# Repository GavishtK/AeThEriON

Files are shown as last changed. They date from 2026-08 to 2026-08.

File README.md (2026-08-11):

<p align="center">
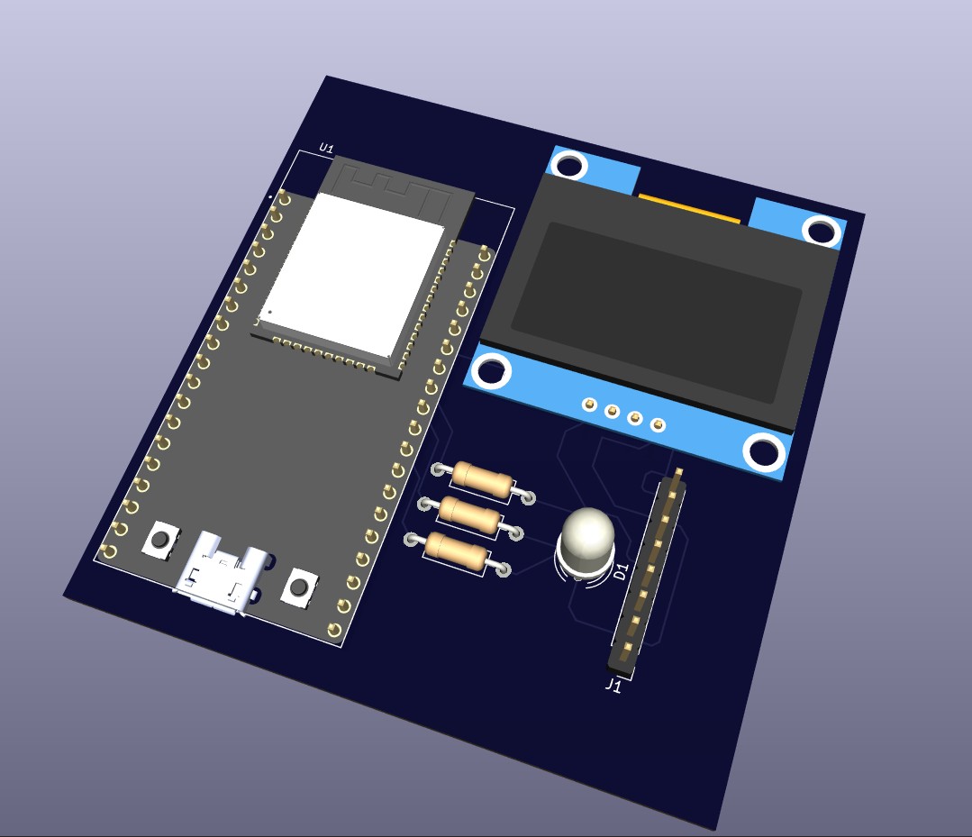
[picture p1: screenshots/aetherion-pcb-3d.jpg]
Aetherion PCB 3D Render
  
</p>

<h1 align="center">AETHERION AI</h1>

<p align="center">
  <b>ESP32-Based Attitude Indicator &amp; Wireless Flight Instrumentation System</b>
  <br/>
  
  
  
  
  
</p>

<p align="center">
  <b>Real-time flight attitude indicator with a wireless OLED display and a full web-based analytics dashboard.</b>
</p>
<p align="center">
  <b>50 Hz telemetry | 25 FPS OLED | 60 FPS horizon | AI analysis | Flight recording &amp; replay | SQLite-quality sensor diagnostics</b>
</p>

---

## Table of Contents

1. [Project Overview](#overview)
2. [System Architecture](#system-architecture)
3. [Data Flow](#data-flow)
4. [Telemetry Protocol](#telemetry-protocol)
5. [Firmware](#firmware)
6. [Dashboard](#dashboard)
7. [Screenshots](#screenshots)
8. [PCB Design](#pcb-design)
9. [Hardware](#hardware)
10. [Quick Start](#quick-start)
11. [Development](#development)
12. [UI Testing](#ui-testing)
13. [License](#license)

---

## Overview 

AETHERION AI is a self-contained, open-source flight instrumentation system built on the ESP32. It combines:

- **Onboard OLED primary flight display (PFD)** — 128×64 monochrome display rendered at 25 FPS
- **Wireless web dashboard** — served directly from the ESP32 over Wi-Fi, accessed via any browser
- **Real-time attitude indicator** — artificial horizon with pitch ladder, roll arc, aircraft symbol, and turn coordinator
- **Flight telemetry** — 50 Hz broadcast of raw IMU data, computed attitude, and G-force over WebSocket
- **Flight recording & replay** — client-side session storage (IndexedDB), CSV/JSON export, and seekable playback
- **AI-powered analysis** — multi-model flight state classification (Random Forest, XGBoost, Neural Network, SVM)
- **Stability & control scoring** — RMS deviation, oscillation analysis, correction rate, and pilot stability metrics
- **Sensor health diagnostics** — saturation, noise, packet-loss, and data-quality analysis

The ESP32 runs in **Access Point mode**, creating its own Wi-Fi network so no router is required. The dashboard is stored on-board in LittleFS flash and served over HTTP, while telemetry is streamed over a WebSocket server at 50 Hz.

---

## System Architecture 

### Firmware Module Architecture

```mermaid
graph LR
    subgraph "firmware/Aetherion"
        A[Aetherion.ino<br/>Main Entry]
        B[config.h<br/>Configuration]
        C[imu.cpp/h<br/>Sensor Driver<br/>MPU6050 + Madgwick]
        D[graphics.cpp/h<br/>OLED Rendering<br/>U8g2 / PFD]
        E[web.cpp/h<br/>HTTP + WS Server<br/>LittleFS]
        F[rgb.cpp/h<br/>LED Status]
    end

    A --> B
    A --> C
    A --> D
    A --> E
    A --> F
    C -->|IMUData| D
    C -->|IMUData| A
    D -->|drawPFD| A
    E -->|handleWebClient| A
    F -->|Status| A
```

### Architecture Diagram (Image)

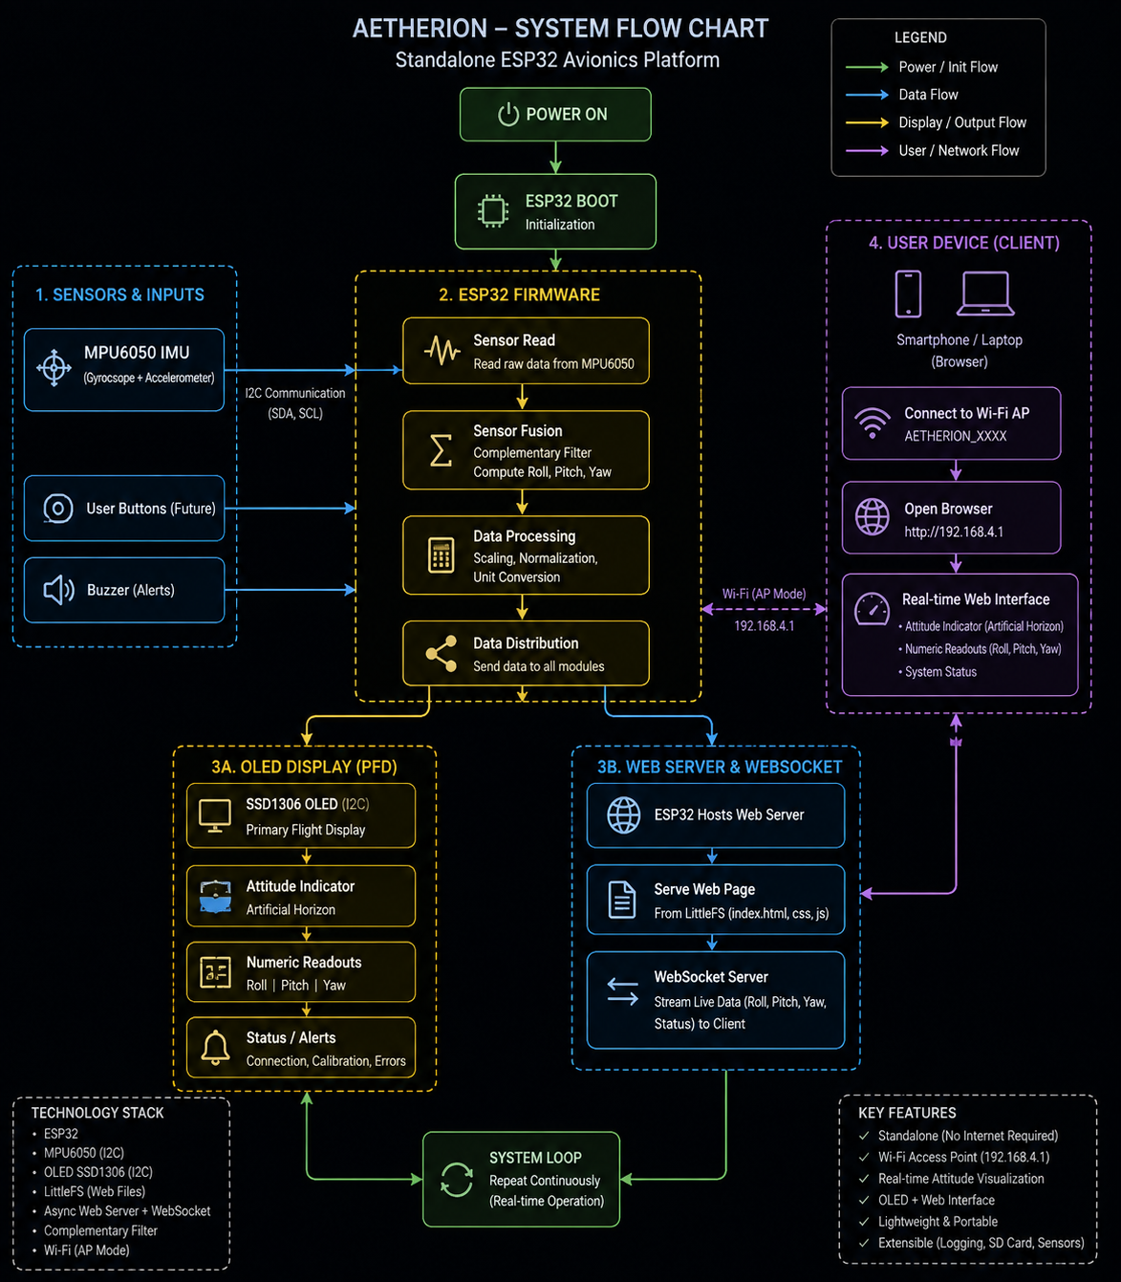
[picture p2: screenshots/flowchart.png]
System Architecture Flowchart


---

## Data Flow 

```mermaid
sequenceDiagram
    participant ESP32 as ESP32
    participant IMU as MPU6050 (I2C)
    participant OLED as OLED Display
    participant Browser as Web Browser
    participant IndexedDB as IndexedDB (Local)

    loop Setup (one-time)
        ESP32->>IMU: Initialize (I2C 0x68)
        ESP32->>IMU: Calibrate (200 samples)
        ESP32->>OLED: Boot Screen → Loading → Ready
        ESP32->>ESP32: Create I2C Mutex
        ESP32->>ESP32: Create oledTask (FreeRTOS, 25 FPS)
        ESP32->>WiFi: softAP("Aetherion", "aetherion123")
        ESP32->>WS: WebSocket Server begin (port 81)
        ESP32->>HTTP: LittleFS mount + WebServer begin (port 80)
    end

    par oledTask (25 FPS, Core 0)
        loop every 40 ms
            oledTask->>IMU: xSemaphoreTake(i2cMutex)
            IMU->>oledTask: Read accel + gyro
            oledTask->>oledTask: Compute roll/pitch (atan2)
            oledTask->>OLED: drawPFD(roll, pitch, gForce)
            oledTask->>oledTask: xSemaphoreGive(i2cMutex)
        end
    end

    par Main Loop (50 Hz)
        loop every 20 ms
            ESP32->>Web: handleWebClient() (HTTP)
            ESP32->>WS: webSocket.loop() (WebSocket)
            ESP32->>IMU: xSemaphoreTake(i2cMutex, 5 ms)
            IMU->>ESP32: updateIMU() — raw accel, gyro, computed attitude
            ESP32->>ESP32: xSemaphoreGive(i2cMutex)
            ESP32->>Browser: WebSocket broadcastTXT(JSON) at 50 Hz
        end
    end

    Note over Browser,DB: Browser receives 50 Hz telemetry
    Browser->>Browser: Parse JSON packet
    Browser->>Browser: Update horizon (60 FPS via requestAnimationFrame)
    Browser->>Browser: Update telemetry readouts (15 Hz)
    Browser->>Browser: Update live graphs (15 FPS)
    Browser->>Browser: Detect flight state (10 Hz rule-based)
    Browser->>IndexedDB: Store snapshot on record
```

### Telemetry Packet Format

Every 20 ms (50 Hz), the ESP32 broadcasts a JSON packet:

```json
{
  "t": 1543210,
  "roll": -4.23,
  "pitch": 2.15,
  "gForce": 1.02,
  "ax": 0.123,
  "ay": -0.045,
  "az": 9.782,
  "gx": 0.001,
  "gy": -0.003,
  "gz": 0.002
}
```

| Field | Type | Unit | Description |
|---|---|---|---|
| `t` | uint32 | ms | ESP32 uptime (for clock sync) |
| `roll` | float  | degrees  | Roll angle (-180° to +180°) |
| `pitch` | float  | degrees  | Pitch angle (-90° to +90°) |
| `gForce`  | float  | G | Resultant G-force (1.0 = level) |
| `ax/ay/az`| float  | m/s² | Accelerometer raw values |
| `gx/gy/gz`| float  | rad/s | Gyroscope raw values |

---

## Firmware 

The ESP32 firmware is an Arduino sketch (`Aetherion.ino`) with modular C++ components.

### File Structure

```
firmware/Aetherion/
├── Aetherion.ino      # Main entry point: setup() + loop()
├── config.h           # Pin assignments, WiFi creds, constants
├── imu.cpp            # MPU6050 driver + sensor fusion
├── imu.h              # IMU data structure + API
├── graphics.cpp       # OLED rendering (PFD, boot screen, loading)
├── graphics.h         # Graphics API declarations
├── web.cpp            # HTTP + WebSocket server (LittleFS)
├── web.h              # Web server API declarations
├── rgb.cpp            # RGB LED status indicator
├── rgb.h              # RGB LED API declarations
├── sync_dashboard.ps1 # Syncs dashboard files to LittleFS data/
└── data/              # Dashboard served from LittleFS
    ├── index.html
    ├── style.css
    └── js/
        ├── app.js           # Core app: WebSocket, render loop
        ├── horizon.js        # Canvas artificial horizon
        ├── graphs.js         # Live telemetry graphs
        ├── flight-state.js   # Rule-based state detection
        ├── recorder.js       # Flight recording + IndexedDB
        ├── analysis.js       # Replay, stability, ML panels
        └── settings.js       # Persistent settings (localStorage)
```

### Key Features

| Feature | Details |
|---|---|
| **IMU Sensing** | MPU6050 accelerometer + gyroscope via I2C (400 kHz) |
| **Attitude Calc.**  | Roll/Pitch via `atan2` with 200-sample static calibration offset |
| **G-Force** | Resultant acceleration vector magnitude normalized to G |
| **OLED Display** | 128×64 SH1106, drawn at 25 FPS via dedicated FreeRTOS task |
| **PFD Elements** | Pitch ladder, roll arc with tick marks, aircraft symbol, turn coord.  |
| **WiFi** | ESP32 in AP mode — SSID `Aetherion`, password `aetherion123` |
| **WebSocket** | Broadcasts JSON telemetry at 50 Hz (port 81) |
| **HTTP Server** | Serves dashboard from LittleFS (port 80) |
| **FreeRTOS** | `oledTask` on Core 0 at priority 1 with I2C mutex |
| **RGB LED** | Red (boot) → Purple (init) → Blue (connecting) → Green (ready) |
| **I2C Mutex** | Serializes access between main loop (IMU read) and oledTask (OLED draw) |

### Boot Sequence

```mermaid
flowchart TD
    A[Power On] --> B[Serial Init 115200]
    B --> C[initDisplay + initRGB]
    C --> D[RGB Red: Boot Screen]
    D --> E[Delay 1500ms]
    E --> F[RGB Purple: Initializing]
    F --> G[initIMU]
    G --> H[calibrateIMU 200 samples]
    H --> I[Wire.setClock 400kHz]
    I --> J[WiFi.softAP]
    J --> K[WebSocket Server on :81]
    K --> L[initFileSystem + initWebServer]
    L --> M[RGB Purple: Loading Screen 0-96]
    M --> N[RGB Blue: Ready Screen]
    N --> O[Delay 1000ms]
    O --> P[RGB Green: Ready]
    P --> Q[Create I2C Mutex]
    Q --> R[Create oledTask FreeRTOS]
    R --> S[Main Loop: 50 Hz]
```

---

## Dashboard 

The web dashboard is a single-page application (SPA) written in vanilla JavaScript with no external framework dependencies. It uses HTML5 Canvas for all rendering and IndexedDB for local session storage.

### Architecture

```mermaid
graph TB
    subgraph "Dashboard Modules"
        App[app.js<br/>Core Engine<br/>WebSocket, Render Loop]
        Horizon[horizon.js<br/>Artificial Horizon<br/>Canvas 2D]
        Graphs[graphs.js<br/>Live Telemetry Graphs<br/>Canvas 2D]
        FlightState[flight-state.js<br/>State Detection<br/>Rule-based]
        Recorder[recorder.js<br/>Flight Recorder<br/>IndexedDB]
        Analysis[analysis.js<br/>Replay + AI Analysis]
        Settings[settings.js<br/>Config + localStorage]
        Style[style.css<br/>Dark Theme UI]
    end

    App --> Horizon
    App --> Graphs
    App --> FlightState
    App --> Recorder
    App --> Analysis
    App --> Settings
    App --> Style
    App -->|WebSocket| ESP32[ESP32 Telemetry]
    Horizon -->|registerCallback horizon| App
    Graphs -->|registerCallback graph| App
    FlightState -->|registerCallback state| App
    Recorder -->|registerCallback packet+graph| App
    Analysis -->|loadSession| Recorder
    Settings -->|load/save| App
```

### Render Loop Architecture

The dashboard uses a **throttled multi-rate render loop** driven by `requestAnimationFrame`:

| Component | Rate | Trigger | Description |
|---|---|---|---|
| Artificial Horizon  | 60 FPS | `requestAnimationFrame` | Canvas redraw, smooth attitude |
| Telemetry Readouts  | 15 Hz  | Time-based throttle | Text updates for accel/gyro/attitude|
| Live Graphs | 15 FPS | Time-based throttle | Canvas graph plots (roll/pitch/G/gyro)|
| Flight State | 10 Hz  | Time-based throttle | Rule-based state detection |
| Diagnostics | 2 Hz | Time-based throttle | Packet count, FPS, latency, uptime  |
| Packet Callbacks | 50 Hz  | On every packet | Recording data capture |

### Tab Navigation

The dashboard has four tabs:

1. **LIVE** — Real-time attitude indicator, telemetry panel, live graphs, flight state, and status bar
2. **RECORD** — Flight recording controls, session management, recording preview graph
3. **ANALYSIS** — Flight replay, stability metrics, control analysis, sensor health, system performance, AI analysis panel
4. **SETTINGS** — Connection configuration, telemetry settings, display options

### Flight States

The rule-based flight state detector identifies these states:

| State | Color | Trigger Condition |
|---|---|---|
| LEVEL | Green | Roll < 30°, pitch < 8°, G within 0.5–1.8 |
| TURNING LEFT | Cyan | Roll < -30° |
| TURNING RIGHT  | Cyan | Roll > +30° |
| CLIMBING | Amber | Pitch > 15° |
| DESCENDING | Amber | Pitch < -15° |
| PITCH-UP | Orange  | Pitch > 8° |
| PITCH-DOWN | Orange  | Pitch < -8° |
| ROLLING | Magenta | |gx|, |gy| > 0.15 or |gz| > 0.1 |
| RECOVERING | Cyan | Roll < 15° and trending toward level |
| UNSTABLE | Red | G-force > 1.8 or < 0.5 |

### AI Analysis Models

The Analysis tab supports four ML models for flight state classification:

| Model | Use Case | Accuracy Estimate |
|---|---|---|
| Random Forest | Fast, robust baseline classification  | ~92% |
| XGBoost | Gradient boosting, handles edge cases | ~94% |
| Neural Network | Deep pattern recognition | ~90% |
| SVM | Linear separability, low compute | ~88% |

### Stability Metrics

| Metric | Description |
|---|---|
| Roll RMS | Root-mean-square roll deviation |
| Pitch RMS | Root-mean-square pitch deviation |
| Angular-rate RMS | RMS of combined gyroscope rates (gx+gy+gz) |
| Roll Peak | Maximum absolute roll |
| Pitch Peak | Maximum absolute pitch |
| G-Force Peak | Maximum G-force recorded |
| Stability Score | Composite 0-100 score: 100 - weighted deviation penalties |
| Data Quality | Sensor health score factoring missing packets, saturation, noise |

### Control Analysis

| Metric | Description |
|---|---|
| Roll Control | RMS-based quality rating (Good/Moderate/Fair/Poor) |
| Pitch Control | RMS-based quality rating |
| Correction Rate | Frequency of roll direction changes per second |
| Oscillation | Std dev of roll deltas (control stability) |
| Recovery | RMS of roll in final 20% of flight (settling quality) |

---

## Screenshots 

### Dashboard — Live Tab

Real-time attitude indicator with artificial horizon, telemetry panel, live graphs, flight state, and status bar:

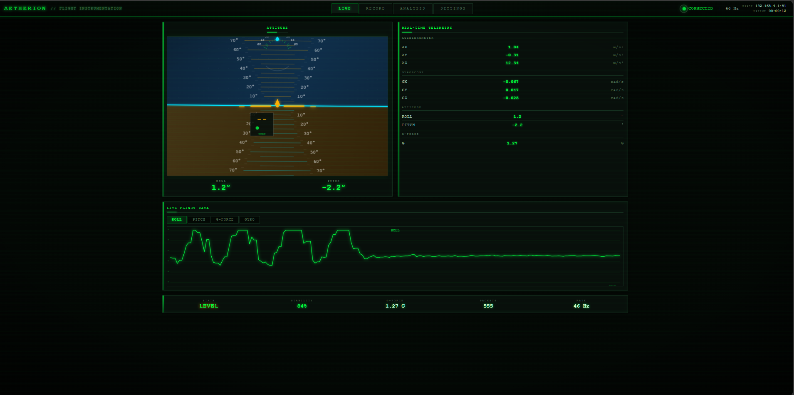
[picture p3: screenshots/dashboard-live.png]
Dashboard Live Tab


### Dashboard — Record Tab

Flight recording controls, session list, and recording preview graph:

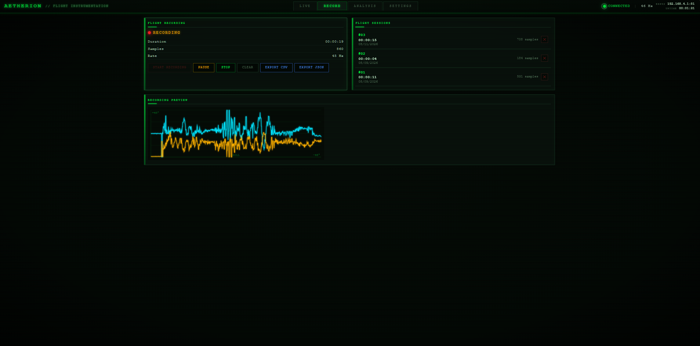
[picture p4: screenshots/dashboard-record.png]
Dashboard Record Tab


### Dashboard — Analysis Tab

Flight replay, stability metrics, control analysis, sensor health, system performance, and AI analysis:

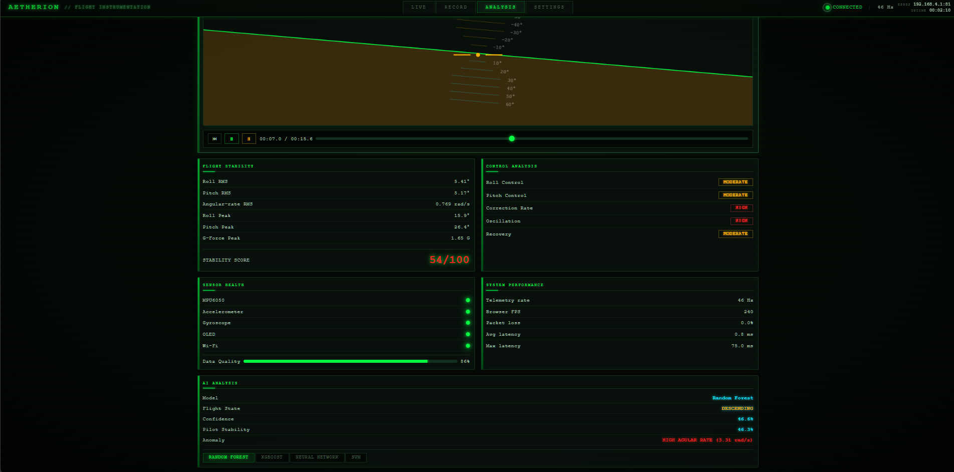
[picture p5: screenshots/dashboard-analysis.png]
Dashboard Analysis Tab


### Dashboard — Settings Tab

Connection settings (ESP32 IP, WebSocket port), telemetry configuration, and display options:

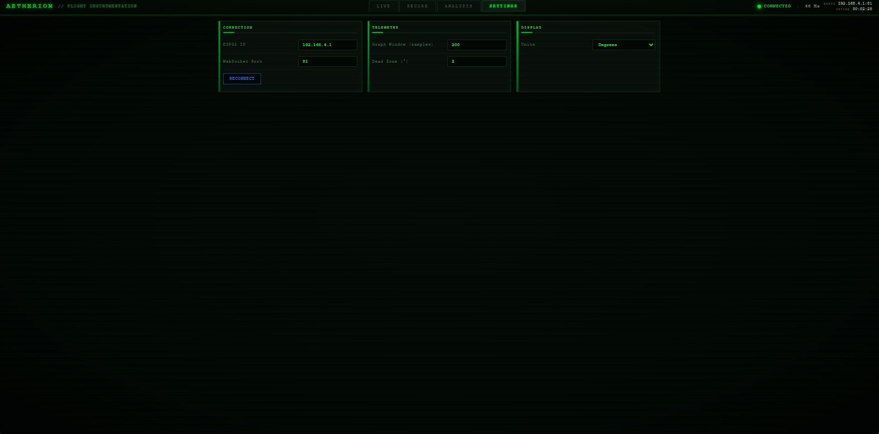
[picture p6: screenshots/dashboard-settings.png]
Dashboard Settings Tab


### UI Test Screenshots

Automated Playwright test captures of all dashboard states:

**Full Dashboard** — Initial render of the complete dashboard:

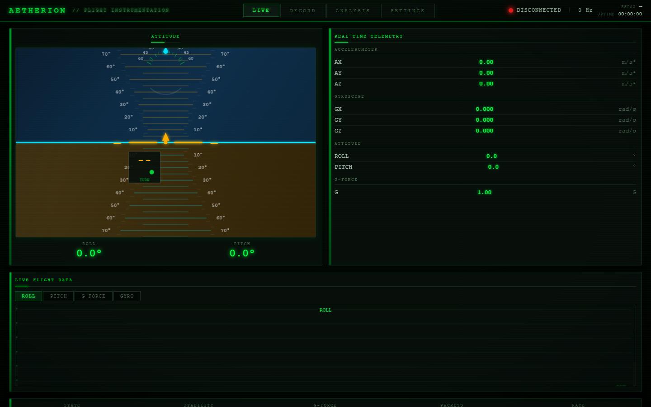
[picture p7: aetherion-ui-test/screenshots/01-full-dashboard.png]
UI Test: Full Dashboard


**Panel Hover** — 3D perspective transform on panel hover:

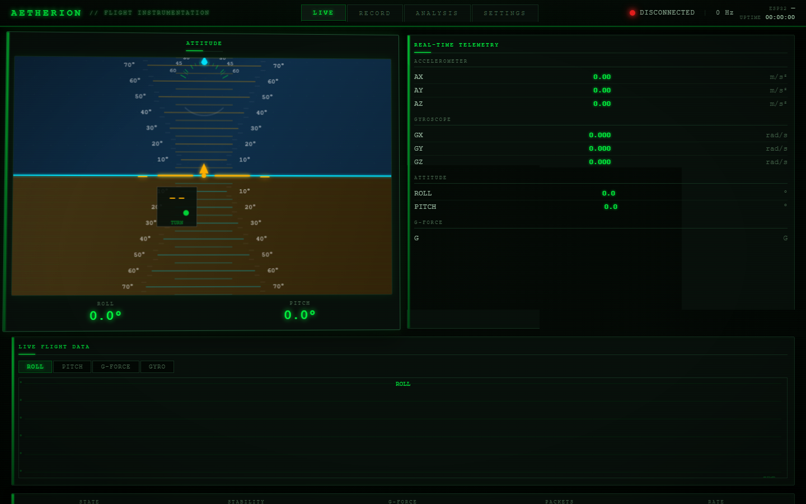
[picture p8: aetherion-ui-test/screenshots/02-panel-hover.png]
UI Test: Panel Hover


**Record Tab** — Recording interface with session list:

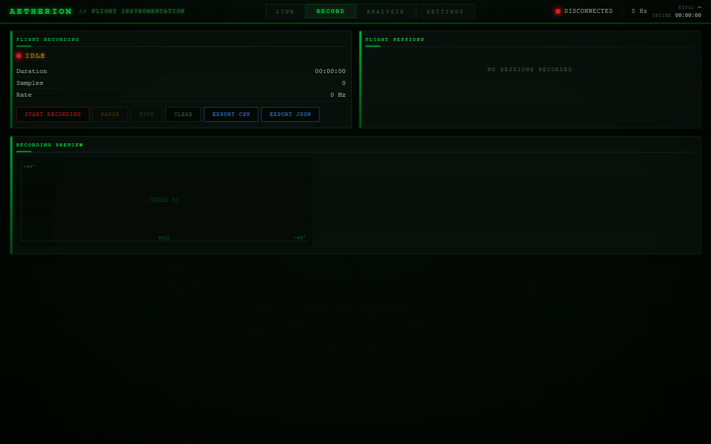
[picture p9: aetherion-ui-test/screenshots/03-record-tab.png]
UI Test: Record Tab


**Analysis Tab** — Flight replay and analysis panels:

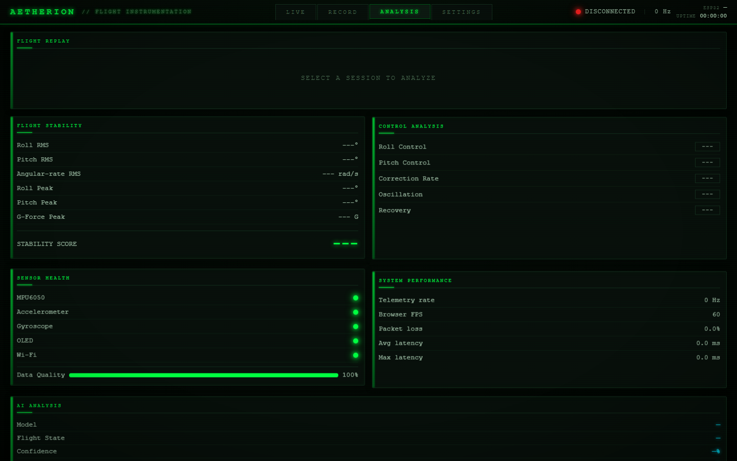
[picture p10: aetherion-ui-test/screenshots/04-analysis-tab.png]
UI Test: Analysis Tab


**Settings Tab** — Configuration panels:

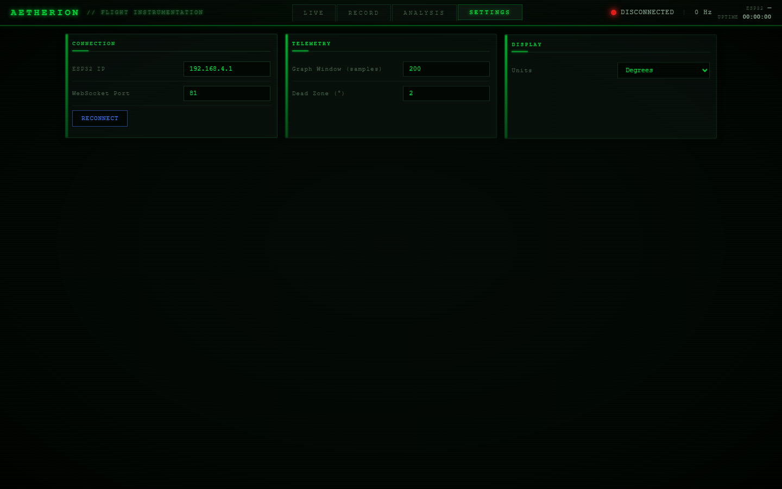
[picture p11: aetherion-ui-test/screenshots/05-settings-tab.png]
UI Test: Settings Tab


**Live Tab (returned)** — Back to live attitude display:

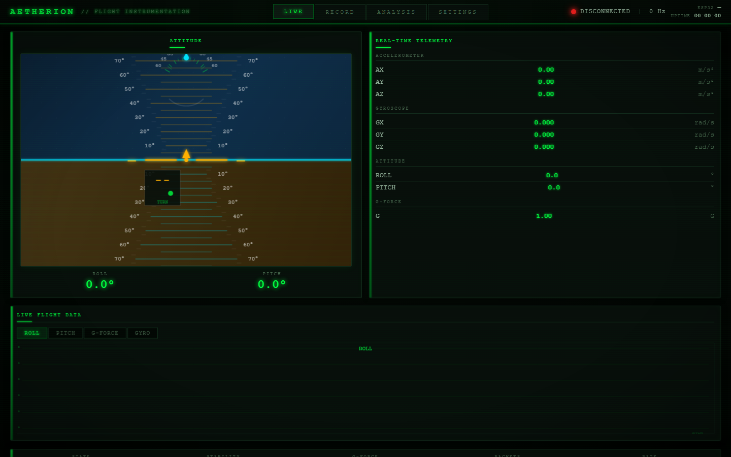
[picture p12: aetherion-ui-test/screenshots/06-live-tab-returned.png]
UI Test: Live Tab Returned


---

## PCB Design 

KiCad project files for the Aetherion hardware. The PCB integrates all components on a single 2-layer board.

### PCB View Gallery

**Schematic** — Complete circuit schematic:

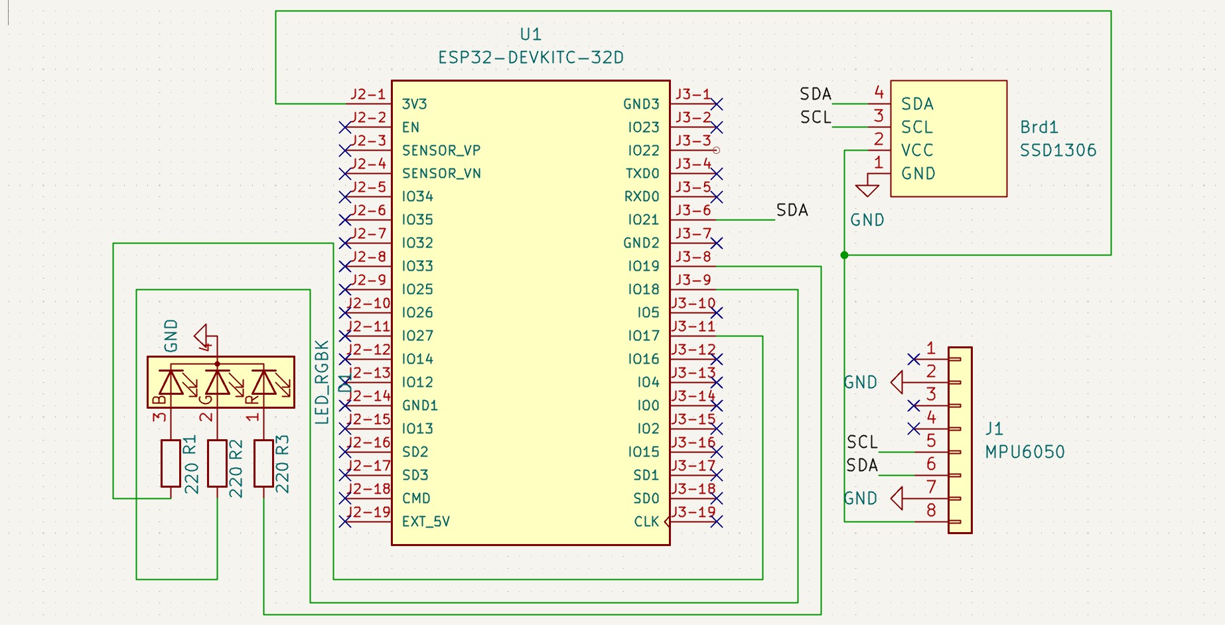
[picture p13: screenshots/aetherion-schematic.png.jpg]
PCB Schematic


**PCB Layout (Routed)** — Top-layer copper routing:

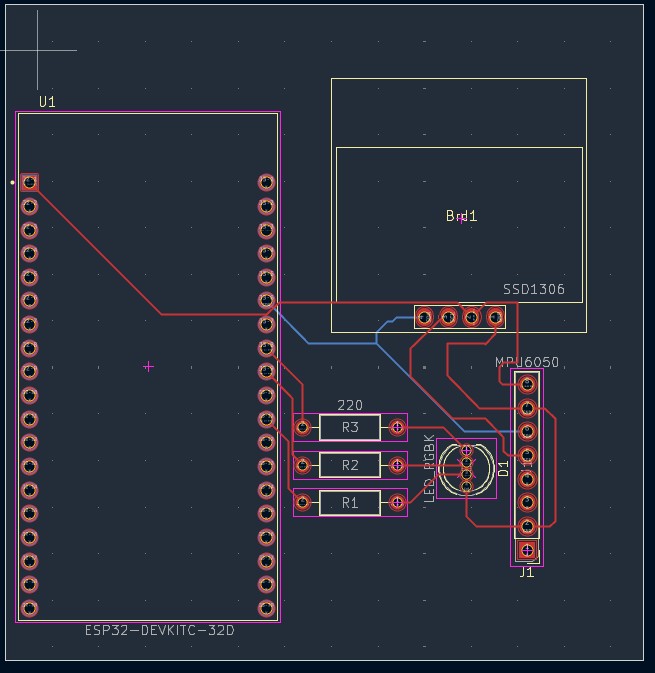
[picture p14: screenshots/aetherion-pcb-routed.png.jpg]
PCB Routed Layout


**3D Render** — Isometric 3D view of the assembled PCB:

PCB 3D Render

**Circuit Diagram (Concept)** — Conceptual circuit overview:

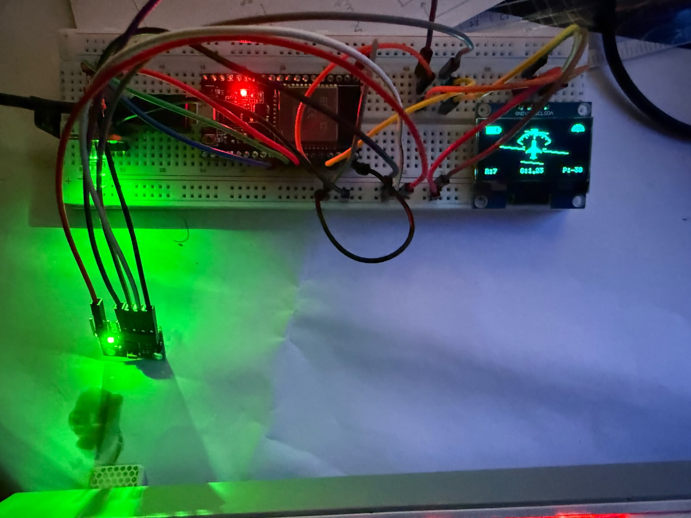
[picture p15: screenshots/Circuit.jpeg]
Circuit Diagram


### PCB File Structure

```
pcb/
├── schematic/           # KiCad schematic files (.kicad_sch)
├── pcb-layout/          # KiCad PCB layout files (.kicad_pcb, .kicad_pro)
├── library/
│   ├── SSD1306-128x64_OLED.kicad_sym           # OLED symbol
│   ├── SSD1306.pretty/
│   │   └── 128x64OLED.kicad_mod               # OLED footprint
│   └── AeroGyro.pretty/
│       └── LED_D5.0mm-4_RGB_AeroGyro.kicad_mod.pretty/
│           └── LED_D5.0mm-4_RGB.kicad_mod     # RGB LED footprint
└── manufacturing/       # Gerber and drill files (for fabrication)
```

### Design Features

| Feature | Details |
|---|---|
| Form Factor | ESP32 DevKit compatible |
| IMU Connector | 4-pin I2C header (SDA, SCL, VCC, GND) for MPU6050 |
| OLED Connector | I2C header (4-pin: SDA, SCL, VCC, GND) for 0.96" SSD1306 display |
| RGB LED | Common cathode, 3-pin current-limited output |
| I2C Pull-ups | 4.7kΩ resistors on SDA and SCL |
| Power | USB-C input with onboard 3.3V regulator |
| Dimensions | Compact handheld form factor |

---

## Hardware 

### Components

| Component | Specification |
|---|---|
| **MCU** | ESP32 DevKit (dual-core, 240 MHz, 520 KB RAM) |
| **IMU** | MPU6050 (3-axis accelerometer + 3-axis gyroscope) |
| **Display** | 0.96" OLED, 128×64 pixels, SSD1306/SH1106, I2C (0x3C) |
| **RGB LED** | Common Cathode, 3-pin (Red: GPIO19, Green: GPIO18, Blue: GPIO17) |
| **WiFi** | 802.11 b/g/n, Access Point mode |
| **I2C Bus** | SDA: GPIO21, SCL: GPIO22, Clock: 400 kHz |
| **WebSocket** | Port 81 — telemetry broadcast |
| **HTTP Server**  | Port 80 — dashboard serving via LittleFS |

---

## Quick Start 

### Prerequisites

- Arduino IDE 2.0+ (or PlatformIO)
- ESP32 board package (`https://raw.githubusercontent.com/espressif/arduino-esp32/gh-pages/package_esp32_index.json`)
- Libraries: `Adafruit MPU6050`, `Adafruit Unified Sensor`, `U8g2`, `ESP Async WebServer`, `LittleFS`, `WebSockets`, `WebServer`

### Setup Steps

1. **Install ESP32 board support** in Arduino IDE:
   - File → Preferences → Additional Boards Manager URLs
   - Add: `https://raw.githubusercontent.com/espressif/arduino-esp32/gh-pages/package_esp32_index.json`
   - Tools → Board → Boards Manager → Install `esp32`

2. **Install required libraries** via Library Manager:
   ```
   Adafruit MPU6050
   Adafruit Unified Sensor
   U8g2 (by olikraus)
   LittleFS_esp32
   WebSockets
   ```

3. **Open the firmware**:
   ```
   firmware/Aetherion/Aetherion.ino
   ```

4. **Upload to ESP32** via Arduino IDE.

5. **Connect to Wi-Fi**:
   - Network: `Aetherion`
   - Password: `aetherion123`

6. **Open the dashboard**:
   - Navigate to `http://192.168.4.1` in any browser

### Syncing Dashboard Updates

When dashboard files are updated during development, sync them to the firmware's LittleFS data folder before uploading:

```powershell
# From the firmware directory
.\Aetherion\sync_dashboard.ps1
```

Then upload via Arduino IDE: `Tools → ESP32 Sketch Data Upload`

---

## Development 

### Project Structure

```
Aetherion/
├── firmware/                    # ESP32 Arduino firmware
│   └── Aetherion/
│       ├── Aetherion.ino        # Main sketch
│       ├── config.h             # Configuration
│       ├── imu.cpp / imu.h      # IMU sensor driver
│       ├── graphics.cpp / graphics.h  # OLED rendering
│       ├── web.cpp / web.h      # HTTP/WebSocket server
│       ├── rgb.cpp / rgb.h      # RGB LED control
│       ├── sync_dashboard.ps1   # Dashboard sync script
│       └── data/                # Dashboard files (LittleFS)
├── dashboard/                   # Standalone web dashboard (dev)
│   ├── index.html
│   ├── style.css
│   └── js/
│       ├── app.js               # Core application
│       ├── horizon.js           # Artificial horizon
│       ├── graphs.js            # Flight graphs
│       ├── flight-state.js      # Flight state detection
│       ├── recorder.js          # Flight recording
│       ├── analysis.js          # AI analysis
│       └── settings.js          # Configuration
├── aetherion-ui-test/           # Playwright UI tests
│   ├── index.html               # Test UI (with GSAP + 3D animations)
│   ├── test-ui.js               # Automated screenshot tests
│   ├── style.css
│   ├── js/
│   │   ├── app.js               # Enhanced: GSAP animations, pulse telemetry
│   │   ├── animations.js        # GSAP animation orchestration
│   │   ├── horizon.js           # Enhanced: 3D perspective transform
│   │   ├── graphs.js            # Enhanced: graph reveal animations
│   │   ├── recorder.js          # Recording + IndexedDB
│   │   ├── flight-state.js      # State detection
│   │   ├── analysis.js          # Analysis + ML panel
│   │   └── settings.js          # Settings
│   └── screenshots/             # Test screenshots
├── pcb/                         # KiCad PCB design files
│   ├── schematic/
│   ├── pcb-layout/
│   ├── library/
│   └── manufacturing/
├── screenshots/                 # Project screenshots & diagrams
├── memory/                      # Memory/knowledge base
├── LICENSE                      # MIT License
├── .gitignore
└── README.md                    # This file
```

### Firmware Development

The firmware follows a modular architecture:

1. **`Aetherion.ino`** — Orchestrates all modules in `setup()` and `loop()`. The main loop is intentionally lightweight: HTTP handling, WebSocket servicing, IMU reads (mutex-protected), and 50 Hz telemetry broadcast.
2. **`imu.cpp`** — MPU6050 driver using Adafruit library. Performs 200-sample calibration on boot, computes roll/pitch via `atan2`, and calculates resultant G-force.
3. **`graphics.cpp`** — U8g2-based OLED renderer. Draws a full PFD (Primary Flight Display) including pitch ladder, roll arc, aircraft symbol, battery indicator, and Wi-Fi icon.
4. **`web.cpp`** — Serves dashboard files from LittleFS over HTTP and broadcasts telemetry over WebSocket (port 81).
5. **`rgb.cpp`** — Simple RGB LED status indicator using direct GPIO control.

### Dashboard Development

The dashboard is a vanilla JavaScript SPA with no framework dependencies. Key architectural decisions:

- **Decoupled architecture**: WebSocket packet reception is completely separate from the render loop. Packets update a central `AG` state object; the render loop reads from it.
- **Throttled multi-rate rendering**: Different UI components update at different rates to balance performance and responsiveness.
- **No external dependencies** (in production firmware): The production dashboard uses zero external libraries. The `aetherion-ui-test/` variant adds GSAP for 3D animation testing.

---

## UI Testing 

The `aetherion-ui-test/` directory contains an enhanced version of the dashboard with GSAP-powered 3D animations, used for visual testing.

### Running Tests

```bash
cd aetherion-ui-test
npm install playwright
node test-ui.js
```

The test script uses Playwright to:

1. Load the dashboard HTML in a headless Chromium browser
2. Capture screenshots of the full dashboard and each tab
3. Test 3D panel hover effects
4. Verify JavaScript module loading (GSAP, Animations, Horizon, etc.)
5. Check for JavaScript errors
6. Validate CSS perspective transforms

### Test Screenshots

| # | Screenshot | Tab | Description |
|---|---|---|---|
| 1 | `01-full-dashboard.png` | Live | Full dashboard initial render |
| 2 | `02-panel-hover.png` | Live | 3D perspective on panel hover |
| 3 | `03-record-tab.png` | Record | Recording interface |
| 4 | `04-analysis-tab.png` | Analysis | Flight replay + analysis panels |
| 5 | `05-settings-tab.png` | Settings | Configuration panels |
| 6 | `06-live-tab-returned.png`  | Live | Return to live attitude display |

---

## License 

MIT License — see [LICENSE](LICENSE) for details.

Copyright (c) 2026 Aetherion

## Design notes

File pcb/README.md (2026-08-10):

# PCB Design

KiCad project files for the AeroGyro hardware.

## Structure

- `schematic/` - KiCad schematic files
- `pcb-layout/` - KiCad PCB layout files
- `footprints/` - Custom component footprints
- `symbols/` - Custom schematic symbols
- `manufacturing/` - Gerber and drill files for fabrication
- `3d/` - 3D model exports

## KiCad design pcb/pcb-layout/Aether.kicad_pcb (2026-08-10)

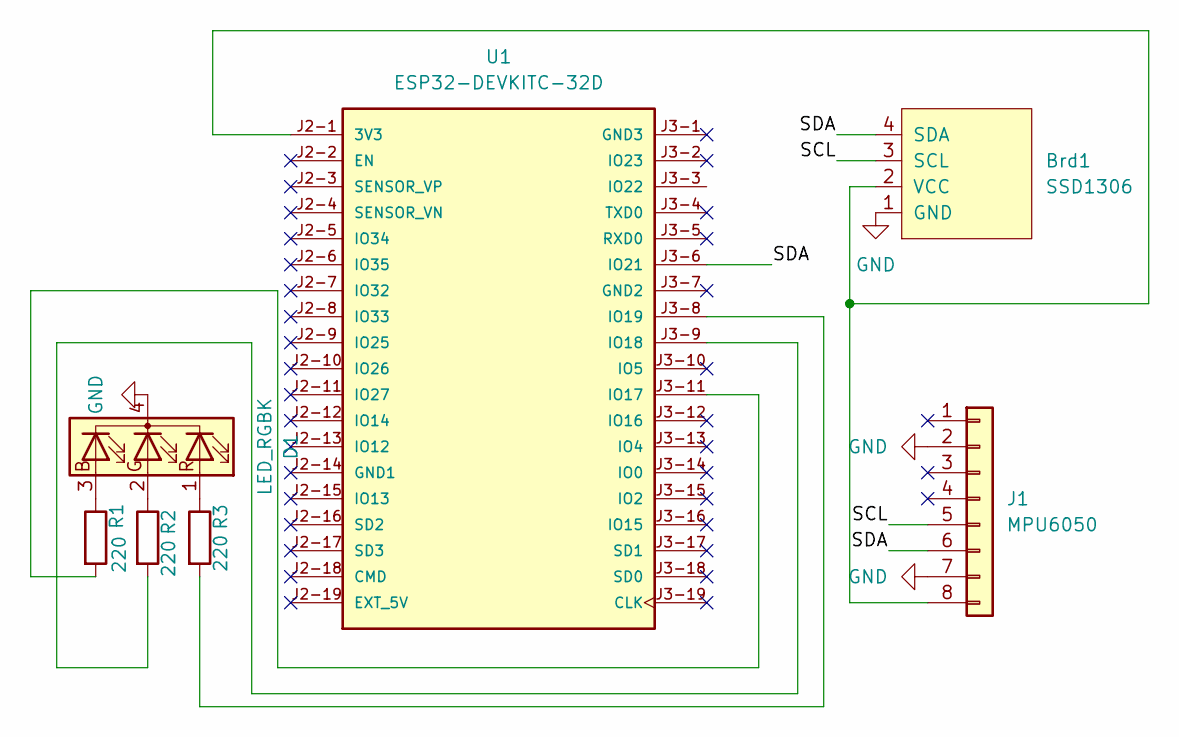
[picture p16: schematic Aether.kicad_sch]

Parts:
Brd1: SSD1306; 128x64OLED
D1: LED_RGBK; LED_D5.0mm-4_RGB
J1: MPU6050; PinHeader_1x08_P2.54mm_Vertical
R1, R2, R3: 220; R_Axial_DIN0207_L6.3mm_D2.5mm_P10.16mm_Horizontal
U1: ESP32-DEVKITC-32D; MODULE_ESP32-DEVKITC-32D; PARTREV V4

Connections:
/SCL: Brd1.3 (SCL), J1.5 (SCL)
/SDA: Brd1.4 (SDA), J1.6 (SDA), U1.J3-6 (IO21)
GND: Brd1.1 (GND), D1.4 (K), J1.2 (AD0), J1.7 (GND)
unnamed: Brd1.2 (VCC), J1.8 (VCC), U1.J2-1 (3V3)
unnamed: D1.3 (BA), R1.1
unnamed: D1.2 (GA), R2.1
unnamed: D1.1 (RA), R3.1
unnamed: R1.2, U1.J3-11 (IO17)
unnamed: R2.2, U1.J3-9 (IO18)
unnamed: R3.2, U1.J3-8 (IO19)

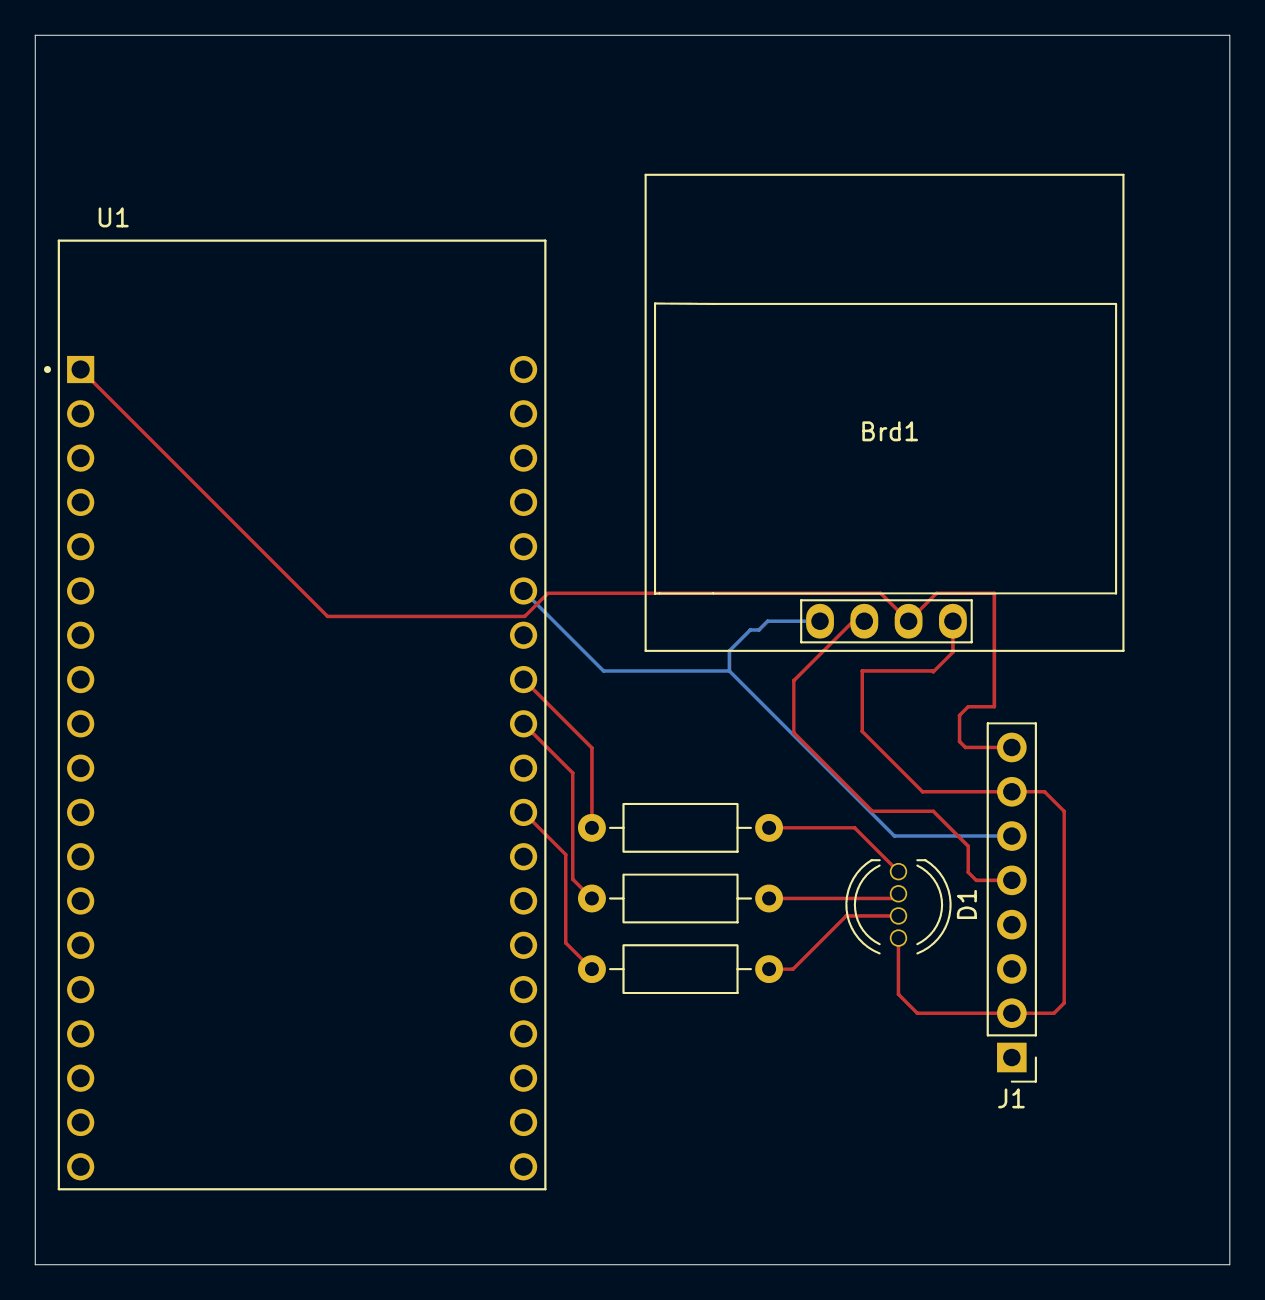
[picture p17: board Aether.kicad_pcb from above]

Board: 2 copper layers, 68.5 x 70.5 mm, 7 parts (0 on the bottom side), 10 nets.

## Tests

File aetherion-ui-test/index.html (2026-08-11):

AETHERION // FLIGHT INSTRUMENTATION

LIVE RECORD ANALYSIS SETTINGS

DISCONNECTED | 0 Hz

ESP32 —

UPTIME 00:00:00

ATTITUDE

ROLL 0.0°

PITCH 0.0°

REAL-TIME TELEMETRY

ACCELEROMETER

AX0.00m/s²

AY0.00m/s²

AZ0.00m/s²

GYROSCOPE

GX0.000rad/s

GY0.000rad/s

GZ0.000rad/s

ATTITUDE

ROLL0.0°

PITCH0.0°

G-FORCE

G1.00G

LIVE FLIGHT DATA

ROLL PITCH G-FORCE GYRO

STATE LEVEL

STABILITY ---%

G-FORCE 1.00 G

PACKETS 0

RATE 0 Hz

FLIGHT RECORDING

IDLE

Duration00:00:00

Samples0

Rate0 Hz

START RECORDING PAUSE STOP CLEAR EXPORT CSV EXPORT JSON

FLIGHT SESSIONS

NO SESSIONS RECORDED

RECORDING PREVIEW

FLIGHT REPLAY

SELECT A SESSION TO ANALYZE

⏮ ▶ ⏸ 00:00.00 / 00:00.00

FLIGHT STABILITY

Roll RMS---°

Pitch RMS---°

Angular-rate RMS--- rad/s

Roll Peak---°

Pitch Peak---°

G-Force Peak--- G

STABILITY SCORE ---

CONTROL ANALYSIS

Roll Control---

Pitch Control---

Correction Rate---

Oscillation---

Recovery---

SENSOR HEALTH

MPU6050

Accelerometer

Gyroscope

OLED

Wi-Fi

Data Quality

100%

SYSTEM PERFORMANCE

Telemetry rate0 Hz

Browser FPS0

Packet loss0.0%

Avg latency0 ms

Max latency0 ms

AI ANALYSIS

Model—

Flight State—

Confidence—%

Pilot Stability—%

Anomaly—

RANDOM FOREST XGBOOST NEURAL NETWORK SVM

CONNECTION

ESP32 IP

WebSocket Port

RECONNECT

TELEMETRY

Graph Window (samples)

Dead Zone (°)

DISPLAY

Units

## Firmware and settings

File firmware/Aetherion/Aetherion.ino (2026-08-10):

#include <WiFi.h>
#include <WebSocketsServer.h>
#include <Wire.h>
#include "freertos/FreeRTOS.h"
#include "freertos/task.h"
#include "freertos/semphr.h"

#include "config.h"
#include "rgb.h"
#include "imu.h"
#include "graphics.h"
#include "web.h"

WebSocketsServer webSocket = WebSocketsServer(81);

/* ============================================================
   FREERTOS — I2C bus is shared by MPU6050 + OLED.
   A mutex serialises access so the OLED task never
   collides with IMU reads in the main loop.
   ============================================================ */

SemaphoreHandle_t i2cMutex = NULL;

// ============================================================
// OLED TASK
//   Runs independently at 25 FPS.
//   Does NOT block wireless telemetry.
// ============================================================

void oledTask(void* param)
{
    const TickType_t period = pdMS_TO_TICKS(1000 / DISPLAY_FPS);

    for (;;)
    {
        if (xSemaphoreTake(i2cMutex, pdMS_TO_TICKS(50)))
        {
            IMUData data = getIMU();
            drawPFD(data);
            xSemaphoreGive(i2cMutex);
        }

        vTaskDelay(period);
    }
}

// ============================================================
// WEBSOCKET EVENT
// ============================================================

void webSocketEvent(
    uint8_t num,
    WStype_t type,
    uint8_t* payload,
    size_t length
)
{
    if (type == WStype_CONNECTED)
    {
        Serial.println("Browser connected!");
    }

    if (type == WStype_DISCONNECTED)
    {
        Serial.println("Browser disconnected!");
    }
}

// ============================================================
// SETUP
// ============================================================

void setup()
{
    Serial.begin(115200);

    // --------------------------------------------------------
    // OLED
    // --------------------------------------------------------

    initDisplay();
    initRGB();

    rgbRed();
    bootScreen();

    delay(1500);

    // Initializing — purple
    rgbPurple();

    // --------------------------------------------------------
    // IMU
    // --------------------------------------------------------

    initIMU();

    calibrateIMU();

    Wire.setClock(400000);  // 400 kHz — reliable for MPU6050 + OLED

    // --------------------------------------------------------
    // Wi-Fi (Access Point mode)
    // The ESP32 creates its own network so the browser
    // connects directly — no external WiFi required.
    // --------------------------------------------------------

    WiFi.mode(WIFI_AP);

    WiFi.softAP(
        AP_SSID,
        AP_PASSWORD,
        AP_CHANNEL,
        AP_HIDDEN,
        AP_MAX_CONN
    );

    Serial.println("Wi-Fi AP started");
    Serial.print("Aetherion AP: ");
    Serial.println(AP_SSID);

    Serial.print("IP: ");
    Serial.println(WiFi.softAPIP());

    // --------------------------------------------------------
    // WebSocket
    // --------------------------------------------------------

    webSocket.begin();
    webSocket.onEvent(webSocketEvent);

    Serial.println("WebSocket server started on port 81");

    // --------------------------------------------------------
    // HTTP Web Server
    // Serves the dashboard files (index.html, CSS, JS) from
    // LittleFS so the browser can load the web UI.
    // --------------------------------------------------------

    initFileSystem();
    initWebServer();

    // --------------------------------------------------------
    // Loading
    // --------------------------------------------------------

    rgbPurple();

    for (int p = 0; p <= 96; p++)
    {
        loadingScreen(p);
        delay(15);
    }

    rgbBlue();
    readyScreen();
    delay(1000);
    rgbGreen();

    // --------------------------------------------------------
    // OLED task — created LAST so loading/ready screens
    // (which also use I2C) finish before the task starts.
    // --------------------------------------------------------

    i2cMutex = xSemaphoreCreateMutex();

    if (i2cMutex != NULL)
    {
        xTaskCreatePinnedToCore(
            oledTask,
            "oledTask",
            4096,
            NULL,
            OLED_TASK_PRIO,
            NULL,
            0
        );
    }
}

// ============================================================
// LOOP
//   Main loop is now purely:
//     1. HTTP web server
//     2. WebSocket networking
//     3. IMU read (I2C, mutex-protected)
//     4. Telemetry broadcast at 50 Hz
//
//   OLED drawing happens in oledTask (separate FreeRTOS task).
// ============================================================

void loop()
{
    // --- HTTP web server (serves dashboard files) ---
    handleWebClient();

    // --- WebSocket networking (no I2C) ---
    webSocket.loop();

    // --- IMU read (I2C mutex-protected) ---
    if (xSemaphoreTake(i2cMutex, pdMS_TO_TICKS(5)))
    {
        updateIMU();
        xSemaphoreGive(i2cMutex);
    }

    // --- Telemetry broadcast at 50 Hz ---
    static unsigned long lastSend = 0;
    unsigned long now = millis();

    if (now - lastSend >= 20)
    {
        lastSend = now;

        IMUData imu = getIMU();

        char data[256];

        snprintf(
            data,
            sizeof(data),

            "{\"t\":%lu,"
            "\"roll\":%.2f,"
            "\"pitch\":%.2f,"
            "\"gForce\":%.2f,"
            "\"ax\":%.3f,"
            "\"ay\":%.3f,"
            "\"az\":%.3f,"
            "\"gx\":%.3f,"
            "\"gy\":%.3f,"
            "\"gz\":%.3f}",

            now,
            imu.roll,
            imu.pitch,
            imu.gForce,
            imu.ax,
            imu.ay,
            imu.az,
            imu.gx,
            imu.gy,
            imu.gz
        );

        webSocket.broadcastTXT(data);
    }

    yield();
}

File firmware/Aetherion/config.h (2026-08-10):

#ifndef CONFIG_H
#define CONFIG_H

// =====================================================
// Project Information
// =====================================================

#define PROJECT_NAME    "Aetherion AI"
#define VERSION         "1.0"

// =====================================================
// OLED
// =====================================================

#define SCREEN_WIDTH    128
#define SCREEN_HEIGHT   64

#define OLED_ADDRESS    0x3C

// =====================================================
// I2C
// =====================================================

#define SDA_PIN         21
#define SCL_PIN         22
#define I2C_CLOCK_HZ    400000

// =====================================================
// MPU6050
// =====================================================

#define MPU_ADDRESS     0x68

// =====================================================
// Wi-Fi (Access Point mode)
// =====================================================

#define AP_SSID         "Aetherion"
#define AP_PASSWORD     "aetherion123"
#define AP_CHANNEL      1
#define AP_HIDDEN       0
#define AP_MAX_CONN     8

// =====================================================
// Web Server (HTTP dashboard)
// =====================================================

#define HTTP_PORT       80

// =====================================================
// RGB LED
// (Common Cathode)
// =====================================================

#define RED_PIN         19
#define GREEN_PIN       18
#define BLUE_PIN        17

// =====================================================
// Display
// =====================================================

#define DISPLAY_FPS     25
#define OLED_TASK_PRIO  1

// =====================================================
// Calibration
// =====================================================

#define CALIBRATION_SAMPLES 500

// =====================================================
// Aircraft Symbol
// =====================================================

#define CENTER_X 64
#define CENTER_Y 32

#endif

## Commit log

2026-08-08 fix: OLED/WebSocket decoupled, RGB sync, WebGL game architecture
    - Decouple OLED (25 FPS) from WebSocket (50 Hz) with independent schedules
    - Add yield() for Wi-Fi background tasks
    - Fix RGB init (was never called) and sync with OLED boot screens
    - Red: boot, Purple: loading, Blue: ready, Green: normal
    - Add Context7 MCP server config
    - Restructure browser game to WebGL + 2D text overlay
    [config.h, rgb.cpp]
2026-08-10 docs: add PCB screenshots and flowchart
2026-08-10 cressida: pre-mission snapshot (mission_20260810_112756)
    [Aether.kicad_pcb, Aether.kicad_sch]
